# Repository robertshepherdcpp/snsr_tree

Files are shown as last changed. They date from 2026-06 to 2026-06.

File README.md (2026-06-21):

# snsr_tree
a tree with all the sensors you need to stay healthy!
 


## inspiration
- i have always wanted some sensors for my room, however, they are expensive and involve constantly checking the readings.
- so i thought it would be cool to make my own, where all these sensors are merged into one thing — and if certain levels were too high, it would actually tell me to change them!
- i wanted it to be something that sits in my room, so i decided to make it the shape of a tree (to blend in with the plants on my desk).

## how to use
1. get the PCB and case printed, and buy all the parts (listed in the BOM — total cost: $82.23)
2. paint the case green as shown in the 3D renders
3. download the audio files (mp3) from this repository and save them onto an SD card (32GB)
4. insert the SD card into the SD card holder on the PCB
5. assemble the case using screws, which also go through the PCB
6. plug into a computer and flash the firmware (in this repository) to the XIAO-ESP32-C6 — easiest via the Arduino IDE
7. keep plugged into the computer, as it is the project's power source
8. use the project and listen out for warnings!

## what it is / how it works
- the snsr_tree takes readings of different environmental levels: CO2, humidity, temperature, and light
- based on those readings, it will alert you to change certain levels — or in some cases do it for you (e.g. when it's too dark)
- keeping you informed about the conditions in your room!
  
## features
- WiFi communication for RTC (real-time clock sync)
- I2C protocol for sensor communication

## screenshots
 
the 3D case:
 


the schematic:
 


the PCB wiring:
 


PCB 3D model:



BOM:
| Name | Price  | Link |
|---|---|---|
| SCD40 | $19.60 | https://www.aliexpress.com/item/1005004251901089.html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 |
| ICS-43434 | $3.43  | https://www.aliexpress.com/item/1005009682961260.html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 |
| MAX98357A Audio Amplifier | $1.32  | https://www.aliexpress.com/item/1005007003802663.html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 |
| MCP23017 | $1.81  | https://www.aliexpress.com/item/1005007892385986.html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 |
| XIAO-ESP32-C6 | $7.11  | https://www.aliexpress.com/item/1005008233414789.html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 |
| micro-sd card holder | $6.74  | https://www.aliexpress.com/item/1005008118445934.html |
| speaker | $0.82  | https://www.lcsc.com/product-detail/C530531.html?s_z=n_q_C530531&globalKeyword=C530531 |
| leds | $2.08  | https://www.aliexpress.com/item/1005010643263450.html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 |
| resistors - 15r | $2.72  | https://www.aliexpress.com/item/1005011892468044.html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 |
| resistors - 10k | $2.72  | https://www.aliexpress.com/item/1005011892468044.html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 |
| resistors - 4.7k | $2.72  | https://www.aliexpress.com/item/1005011892468044.html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 |
| resistors - 100k | $2.74  | https://www.aliexpress.com/item/1005011892468044.html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 |
| capcitor - 100nf | $0.76  | https://www.aliexpress.com/item/32371454429.html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 |
| capacitor - 10uF | $1.24  | https://www.aliexpress.com/item/1005007137284660.html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 |
| capacitor - 4.7uF | $1.24  | https://www.aliexpress.com/item/1005007137284660.html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 |
| capacitor - 1uF | $1.24  | https://www.aliexpress.com/item/1005007137284660.html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 |
| ldr | $1.02  | https://www.aliexpress.com/item/1005004112010040.html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 |
| m2 12mm screws | $2.11  | https://www.aliexpress.com/item/1005008143416203.html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 |
| pcb fabrication | $10.10 | https://cart.jlcpcb.com/quote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 |
| shipping | $10.71 | https://cart.jlcpcb.com/quote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 |
| total cost | $82.23 | - |

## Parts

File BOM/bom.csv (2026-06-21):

Name | Price | Link
SCD40 | $19.60 | https://www.aliexpress.com/item/1005004251901089.html?curPageLogUid=Gt4emBnw6aWf
ICS-43434 | $3.43 | https://www.aliexpress.com/item/1005009682961260.html?curPageLogUid=vnISMVQXcKGG
MAX98357A Audio Amplifier | $1.32 | https://www.aliexpress.com/item/1005007003802663.html?curPageLogUid=jVDx2fWExivP
MCP23017 | $1.81 | https://www.aliexpress.com/item/1005007892385986.html?curPageLogUid=5EILj2DePQUk
XIAO-ESP32-C6 | $7.11 | https://www.aliexpress.com/item/1005008233414789.html?curPageLogUid=3Z71R6KGLr0g
micro-sd card holder | $6.74 | https://www.aliexpress.com/item/1005008118445934.html
speaker | $0.82 | https://www.lcsc.com/product-detail/C530531.html?s_z=n_q_C530531&globalKeyword=C530531
leds | $2.08 | https://www.aliexpress.com/item/1005010643263450.html?curPageLogUid=BF1YAVMOhfXj
resistors - 15r | $2.72 | https://www.aliexpress.com/item/1005011892468044.html?curPageLogUid=lUmGxkF3KGzQ
resistors - 10k | $2.72 | https://www.aliexpress.com/item/1005011892468044.html?curPageLogUid=lUmGxkF3KGzQ
resistors - 4.7k | $2.72 | https://www.aliexpress.com/item/1005011892468044.html?curPageLogUid=lUmGxkF3KGzQ
resistors - 100k | $2.74 | https://www.aliexpress.com/item/1005011892468044.html?curPageLogUid=lUmGxkF3KGzQ
capcitor - 100nf | $0.76 | https://www.aliexpress.com/item/32371454429.html?curPageLogUid=dIjc8NwSzsQi
capacitor - 10uF | $1.24 | https://www.aliexpress.com/item/1005007137284660.html?curPageLogUid=9b90RMqDifxh
capacitor - 4.7uF | $1.24 | https://www.aliexpress.com/item/1005007137284660.html?curPageLogUid=9b90RMqDifxh
capacitor - 1uF | $1.24 | https://www.aliexpress.com/item/1005007137284660.html?curPageLogUid=9b90RMqDifxh
ldr | $1.02 | https://www.aliexpress.com/item/1005004112010040.html?curPageLogUid=cZMJc4zObGdm
m2 12mm screws | $2.11 | https://www.aliexpress.com/item/1005008143416203.html?curPageLogUid=cFyM0bsjev7p
pcb fabrication | $10.10 | https://cart.jlcpcb.com/quote?stencilLayer=2&stencilWidth=100&stencilLength=100&stencilCounts=5&plateType=1
shipping | $10.71 | https://cart.jlcpcb.com/quote?stencilLayer=2&stencilWidth=100&stencilLength=100&stencilCounts=5&plateType=1
total cost | $82.23 | -

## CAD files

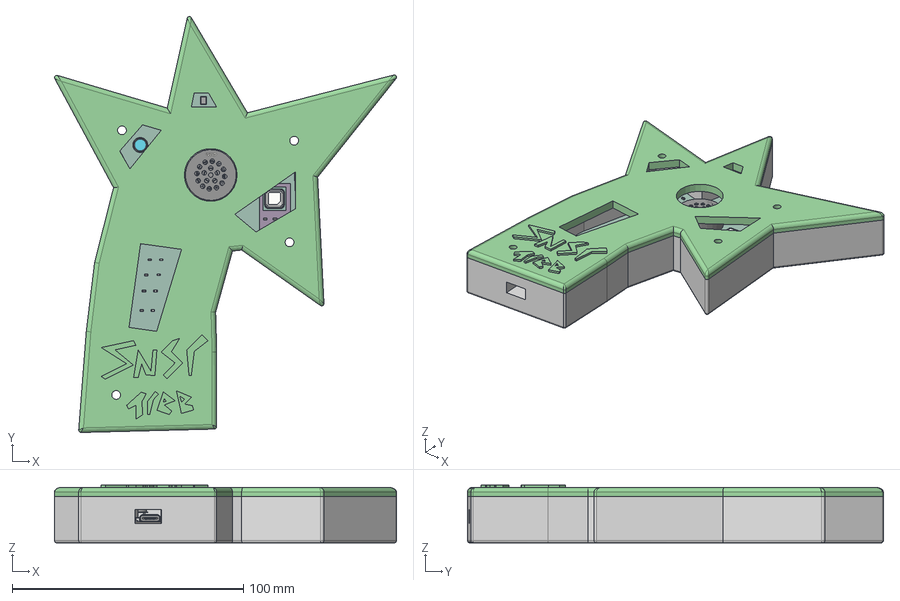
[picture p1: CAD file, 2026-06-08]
3d/snsr_tree v2.step
148.0 x 180.0 x 25.0 mm
SPK-TH_BD23.0-P10.00-D0.8-L-RD
InvenSense_ICS-43434-6_3.5x2.65mm
LED_0603_1608Metric x 4
R_LDR_D6.4mm_P3.4mm_Vertical
R_0603_1608Metric x 8
QFN-28_L6.0-W6.0-P0.65-BL-EP3.7
C_0603_1608Metric
microSD_HC_Hirose_DM3AT-SF-PEJM5
environment_proj_PCB
BOSS-EXTRUDE14_8_
BOSS-EXTRUDE7_4_
BOSS-EXTRUDE7_3_
BOSS-EXTRUDE14_4_
BOSS-EXTRUDE14_2_
BOSS-EXTRUDE14_11_
BOSS-EXTRUDE7_7_
BOSS-EXTRUDE14_9_
BOSS-EXTRUDE14_3_
BOSS-EXTRUDE14_7_
MIRROR2
BOSS-EXTRUDE14_5_
BOSS-EXTRUDE14_12_
BOSS-EXTRUDE7_8_
BOSS-EXTRUDE7_1_
BOSS-EXTRUDE14_10_
BOSS-EXTRUDE7_9_
BOSS-EXTRUDE14_6_
BOSS-EXTRUDE14_1_
BOSS-EXTRUDE7_6_
BOSS-EXTRUDE7_2_
CUT-EXTRUDE5
BOSS-EXTRUDE7_5_
Shield
Pins x 2
U.FL-R-SMT-1_10_ v1
Komponente1
Komponente1 (1)
Komponente2
Komponente3

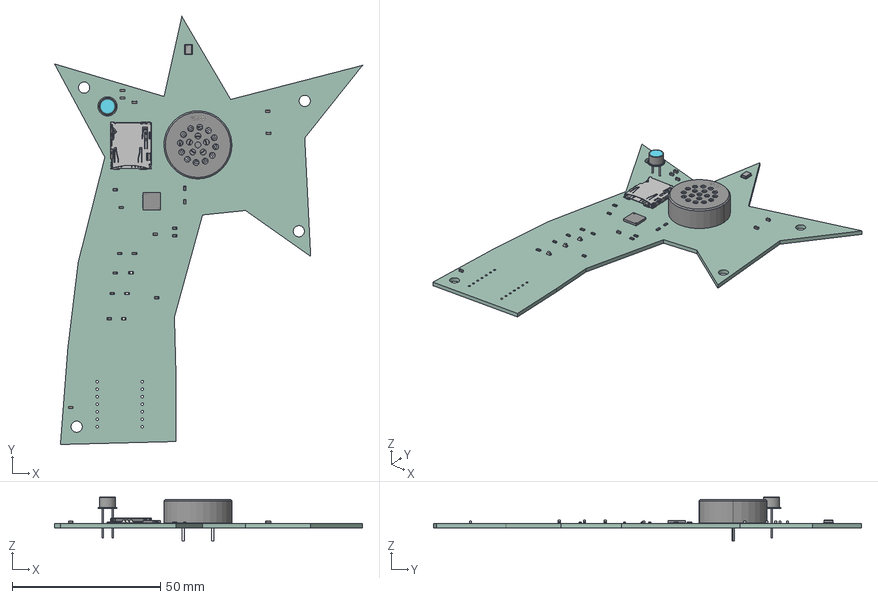
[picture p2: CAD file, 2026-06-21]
PCB/environment_proj.step
104.0 x 144.5 x 14.8 mm
SPK-TH_BD23.0-P10.00-D0.8-L-RD
R_0603_1608Metric x 12
InvenSense_ICS-43434-6_3.5x2.65mm
C_0603_1608Metric x 7
LED_0603_1608Metric x 3
R_LDR_D6.4mm_P3.4mm_Vertical
QFN-28_L6.0-W6.0-P0.65-BL-EP3.7
microSD_HC_Hirose_DM3AT-SF-PEJM5
environment_proj_PCB

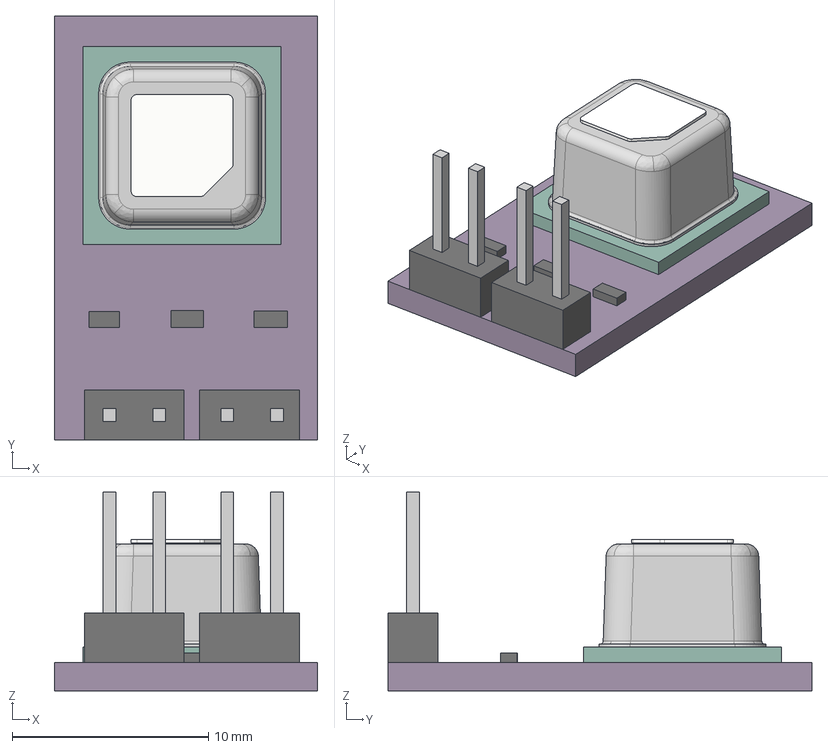
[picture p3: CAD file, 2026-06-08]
3d/scd40 v7.step
13.4 x 21.6 x 10.1 mm
Komponente1
Komponente1 (1)
Komponente2
Komponente3

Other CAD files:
3d/environment_proj.step
3d/snsr_tree v2.f3z

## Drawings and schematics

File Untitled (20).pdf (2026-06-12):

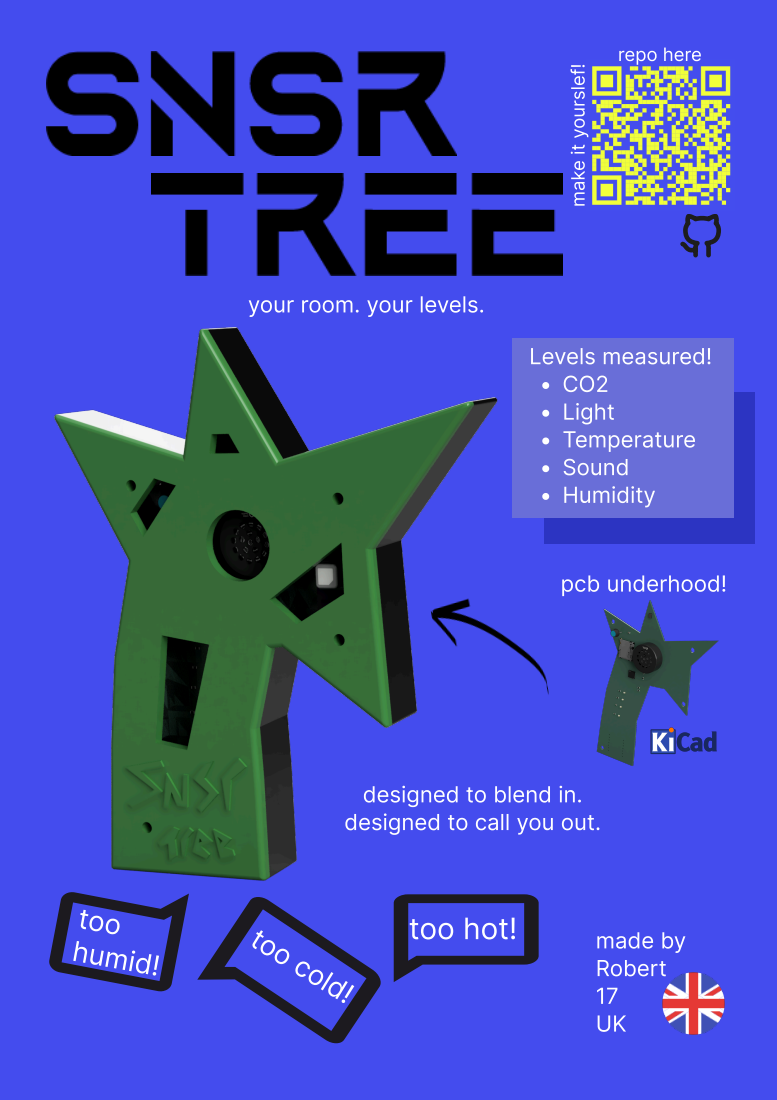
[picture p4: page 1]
repo here; Levels measured! CO2 Light Temperature; Sound Humidity; pcb underhood!; too humid!; made by; Robert 17 UK

make it yourslef!

your room. your levels.

designed to blend in.
designed to call you out.

too hot! too cold!

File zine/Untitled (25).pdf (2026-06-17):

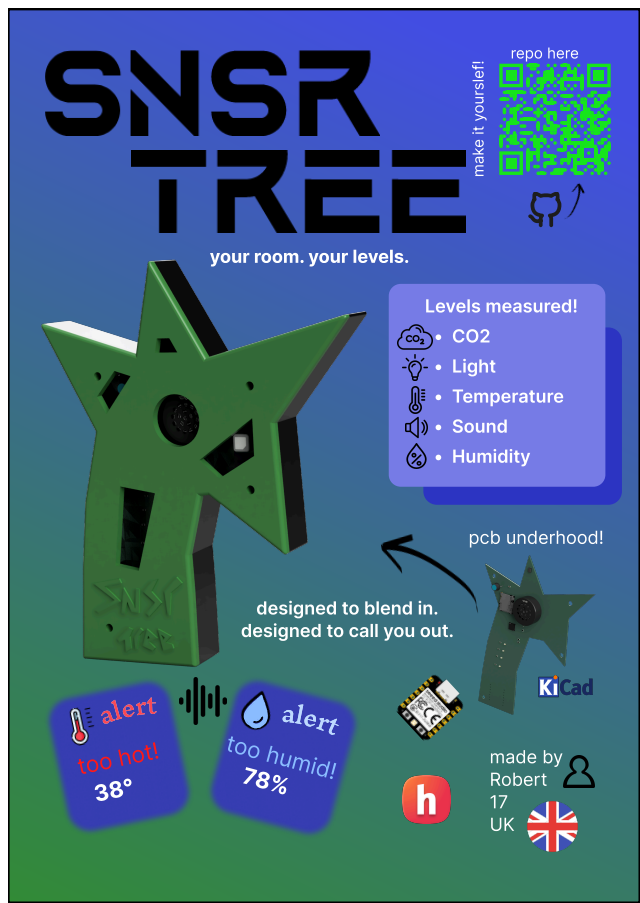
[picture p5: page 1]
repo here; Levels measured!; Light; Temperature; Sound; Humidity; pcb underhood!; too hot! too hot!; too humid!; made by; Robert

make it yourslef!

your room. your levels.

designed to blend in.
designed to call you out.

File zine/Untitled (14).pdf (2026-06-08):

# snsrtree

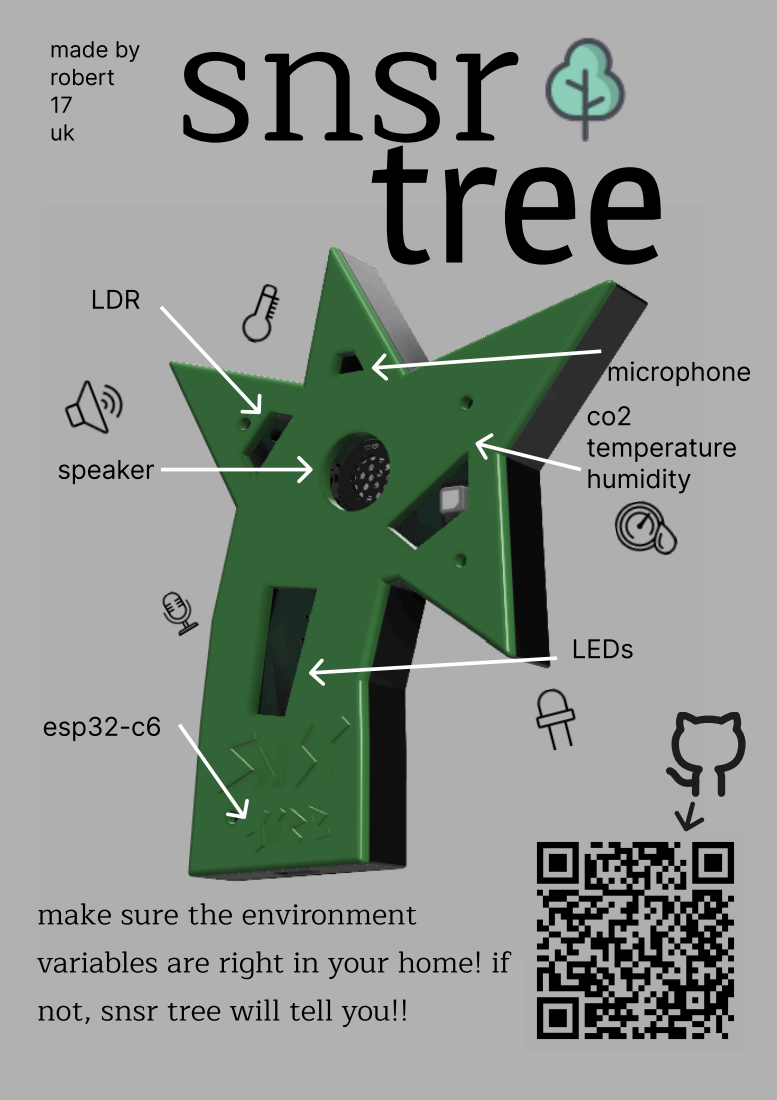
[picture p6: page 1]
made by robert 17 uk; LDR; speaker; microphone; co2 temperature humidity; esp32-c6; LEDs

make sure the environment
variables are right in your home! if
not, snsr tree will tell you!!

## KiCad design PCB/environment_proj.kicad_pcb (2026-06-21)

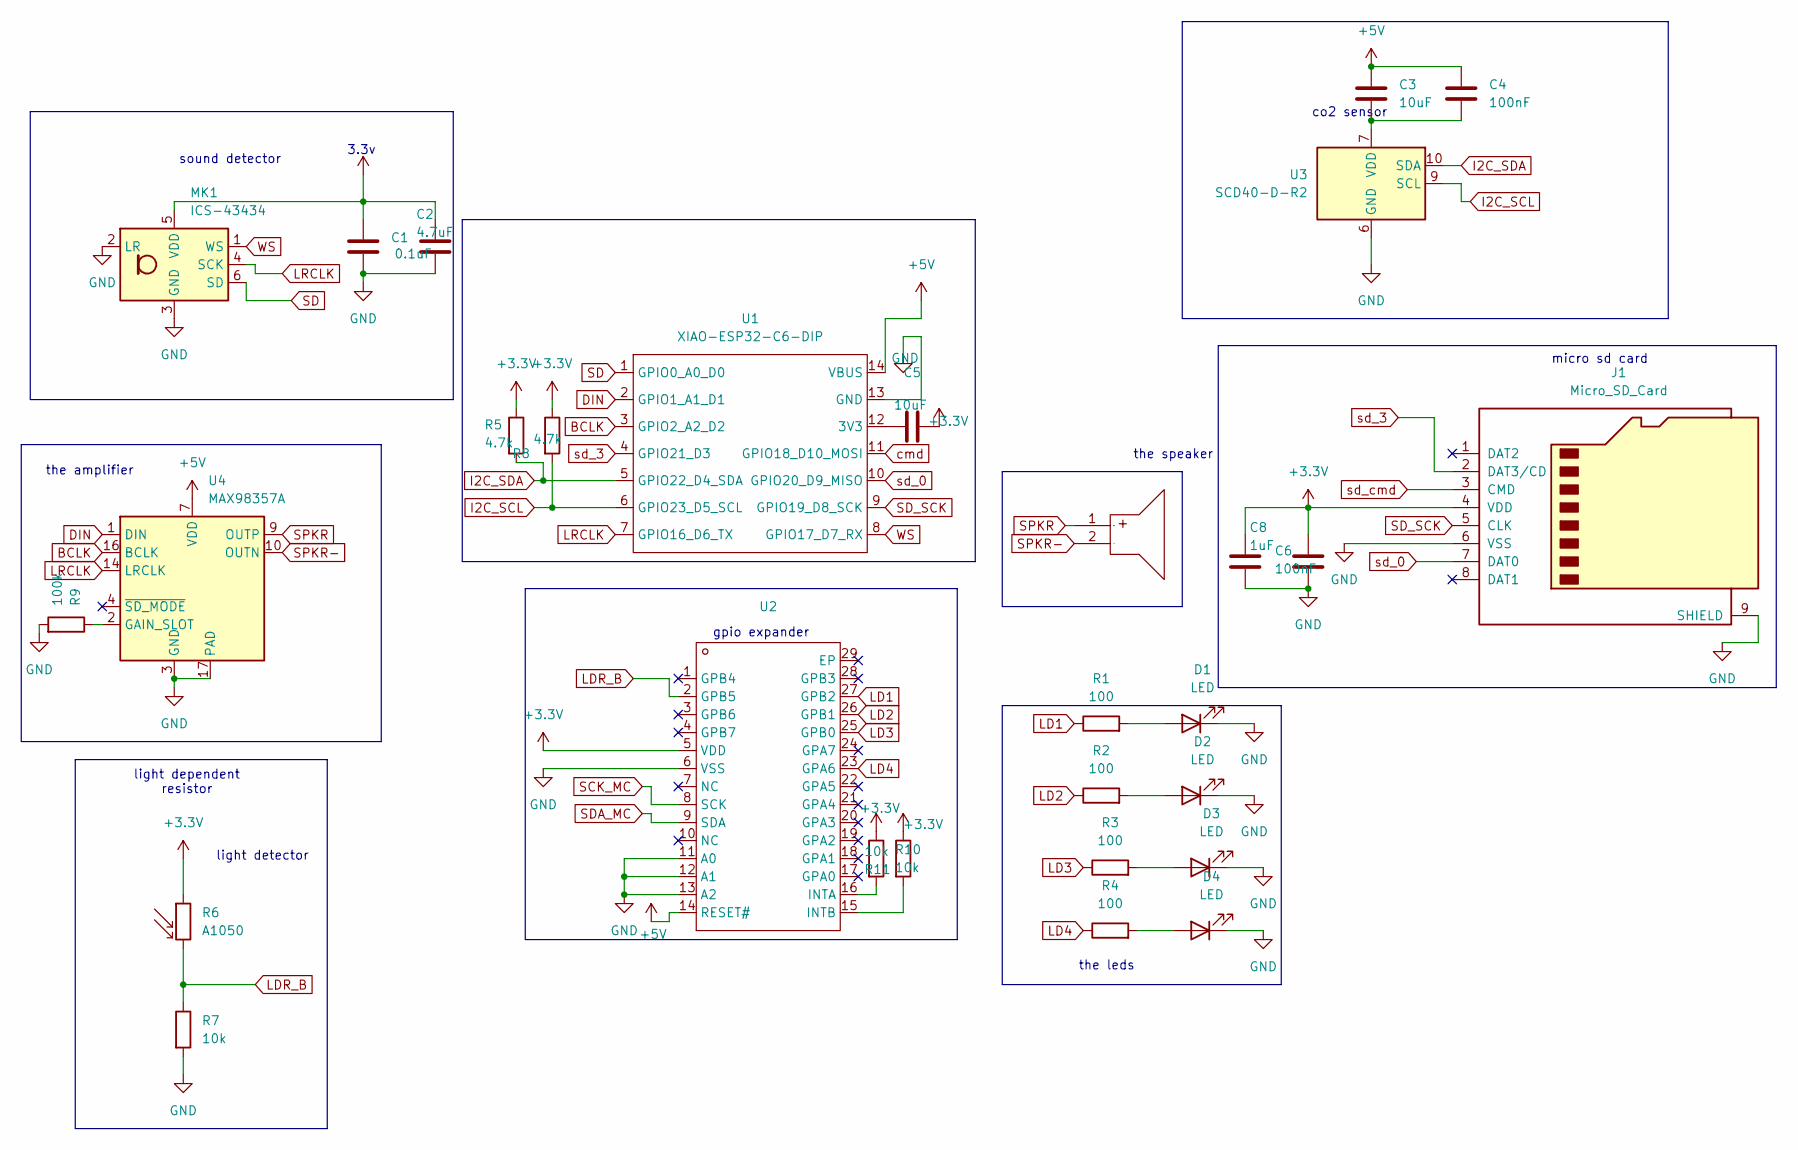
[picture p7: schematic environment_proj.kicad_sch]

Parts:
C1: 0.1uF; C_0603_1608Metric_Pad1.08x0.95mm_HandSolder
C2: 4.7uF; C_0603_1608Metric
C3, C5: 10uF; C_0603_1608Metric
C4, C6: 100nF; C_0603_1608Metric
C8: 1uF; C_0603_1608Metric
D1: LED; R_0603_1608Metric_Pad0.98x0.95mm_HandSolder
D2, D3, D4: LED; LED_0603_1608Metric_Pad1.05x0.95mm_HandSolder
J1: Micro_SD_Card; microSD_HC_Hirose_DM3AT-SF-PEJM5
MK1: ICS-43434; InvenSense_ICS-43434-6_3.5x2.65mm
R1, R2, R3, R4: 100; R_0603_1608Metric_Pad0.98x0.95mm_HandSolder
R5, R8: 4.7k; R_0603_1608Metric_Pad0.98x0.95mm_HandSolder
R6: A1050; R_LDR_D6.4mm_P3.4mm_Vertical
R7, R10, R11: 10k; R_0603_1608Metric_Pad0.98x0.95mm_HandSolder
R9: 100k; R_0603_1608Metric_Pad0.98x0.95mm_HandSolder
SPK4: SPK-TH_BD23.0-P10.00-D0.8-L-RD; Manufacturer Part GSPK2307P-8R1W; LCSC Part Name 23mm 8Ω
U1: XIAO-ESP32-C6-DIP
U2: QFN-28_L6.0-W6.0-P0.65-BL-EP3.7; Manufacturer Part MCP23017T-E/ML; LCSC Part Name 16位带串行接口的I/O扩展器
U3: SCD40-D-R2; Sensirion_SCD4x-1EP_10.1x10.1mm_P1.25mm_EP4.8x4.8mm
U4: MAX98357A; TQFN-16-1EP_3x3mm_P0.5mm_EP1.23x1.23mm

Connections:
+3.3V: C1.1, C2.1, C5.2, C6.1, C8.1, J1.4 (VDD), MK1.5 (VDD), R5.1, R6.1, R8.1, R10.1, R11.1, U2.5 (VDD)
+5V: C3.1, C4.1, U1.14 (VBUS), U2.14 (RESET#), U4.7 (VDD), U4.8 (VDD)
BCLK: U1.3 (GPIO2_A2_D2), U4.16 (BCLK)
DIN: U1.2 (GPIO1_A1_D1), U4.1 (DIN)
GND: C1.2, C2.2, C6.2, C8.2, D1.1 (K), D2.1 (K), D3.1 (K), D4.1 (K), J1.6 (VSS), J1.9 (SHIELD), MK1.2 (LR), MK1.3 (GND), R7.2, R9.2, U1.13 (GND), U2.6 (VSS), U2.11 (A0), U2.12 (A1), U2.13 (A2), U3.6 (GND), U3.20 (GND), U3.21 (GND), U4.3 (GND), U4.11 (GND), U4.15 (GND), U4.17 (PAD)
I2C_SCL: R8.2, U1.6 (GPIO23_D5_SCL), U3.9 (SCL)
I2C_SDA: R5.2, U1.5 (GPIO22_D4_SDA), U3.10 (SDA)
LD1: R1.1, U2.27 (GPB2)
LD2: R2.1, U2.26 (GPB1)
LD3: R3.1, U2.25 (GPB0)
LD4: R4.1, U2.23 (GPA6)
LDR_B: R6.2, R7.1, U2.2 (GPB5)
LRCLK: MK1.4 (SCK), U1.7 (GPIO16_D6_TX), U4.14 (LRCLK)
unnamed: C3.2, C4.2, U3.7 (VDD), U3.19 (VDD)
unnamed: D1.2 (A), R1.2
unnamed: D2.2 (A), R2.2
unnamed: D3.2 (A), R3.2
unnamed: D4.2 (A), R4.2
unnamed: C5.1, U1.12 (3V3)
unnamed: R10.2, U2.16 (INTA)
unnamed: R11.2, U2.15 (INTB)
unnamed: R9.1, U4.2 (GAIN_SLOT)
SCK_MC: U2.8 (SCK)
SD: MK1.6 (SD), U1.1 (GPIO0_A0_D0)
SDA_MC: U2.9 (SDA)
SD_SCK: J1.5 (CLK), U1.9 (GPIO19_D8_SCK)
SPKR: SPK4.1 (+), U4.9 (OUTP); also elsewhere on the board
SPKR-: SPK4.2 (-), U4.10 (OUTN)
WS: MK1.1 (WS), U1.8 (GPIO17_D7_RX)
cmd: U1.11 (GPIO18_D10_MOSI)
sd_0: J1.7 (DAT0), U1.10 (GPIO20_D9_MISO)
sd_3: J1.2 (DAT3/CD), U1.4 (GPIO21_D3)
sd_cmd: J1.3 (CMD)

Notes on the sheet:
the amplifier
light detector
the speaker
micro sd card
3.3v
co2 sensor
the leds
gpio expander
sound detector
light dependent resistor

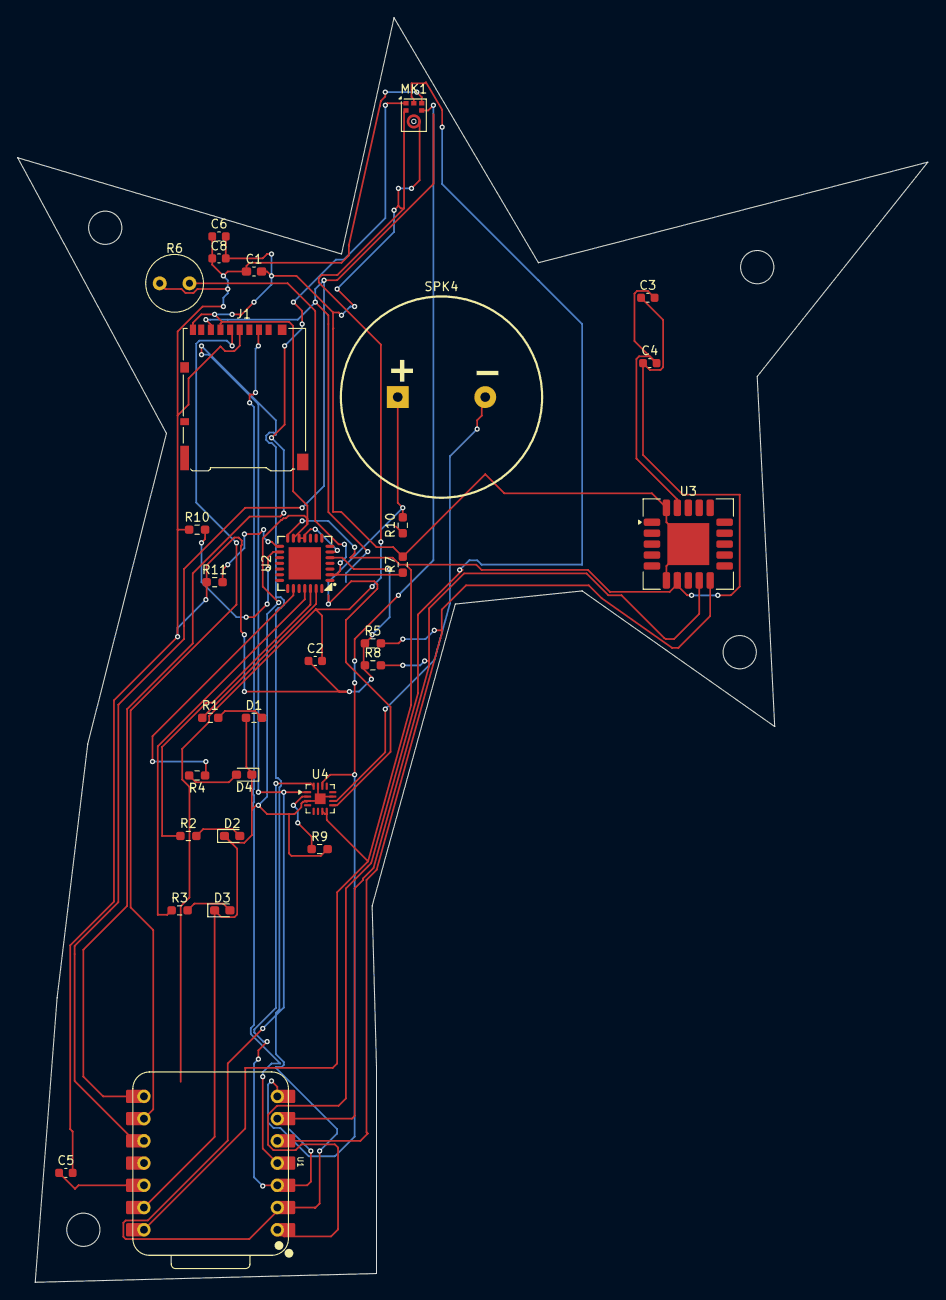
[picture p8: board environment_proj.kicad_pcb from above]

Board: 2 copper layers, 104.0 x 144.5 mm, 30 parts (0 on the bottom side), 29 nets.

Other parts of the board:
R10#2: 8; R_0603_1608Metric_Pad0.98x0.95mm_HandSolder

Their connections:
SPKR: R10#2.2; also elsewhere on the board

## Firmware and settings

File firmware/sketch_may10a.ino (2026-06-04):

#include <Wire.h>
#include <Audio.h>
#include <SPI.h>
#include <Wire.h>
#include <Arduino.h>
#include <SensirionI2cScd4x.h>
#include <SD.h>
#include <Adafruit_MCP23X17.h>

// microphone stuff
#include "I2SSampler.h"

i2s_config_t i2s_config = {
  .mode = (i2s_mode_t)(I2S_MODE_MASTER | I2S_MODE_RX),
  .sample_rate = 16000,
  .bits_per_sample = I2S_BITS_PER_SAMPLE_32BIT,
  .channel_format = I2S_CHANNEL_FMT_ONLY_LEFT,
  .communication_format = i2s_comm_format_t(I2S_COMM_FORMAT_I2S),
  .intr_alloc_flags = ESP_INTR_FLAG_LEVEL1,
  .dma_buf_count = 4,
  .dma_buf_len = 1024,
  .use_apll = false,
  .tx_desc_auto_clear = false,
  .fixed_mclk = 0
};

// i2s pins
i2s_pin_config_t i2s_pins = {
  .bck_io_num = GPIO_NUM_5,
  .ws_io_num = GPIO_NUM_19,
  .data_out_num = I2S_PIN_NO_CHANGE,
  .data_in_num = GPIO_NUM_18
};

I2SSampler *i2s_sampler = NULL;

// for getting the time via wifi:
#include <WiFi.h>
#include <NTPClient.h>
#include <WiFiUdp.h>

// replace with your network credentials!! or else the project wont work... needed to get the time.
const char *ssid = "REPLACE_WITH_YOUR_SSID";
const char *password = "REPLACE_WITH_YOUR_PASSWORD";

// Define NTP Client to get time
WiFiUDP ntpUDP;
NTPClient timeClient(ntpUDP);

// Variables to save date and time
String formattedDate;
String dayStamp;
String timeStamp;

// on the esp32

#define LDR_B 6

// however need to check with these that i can just wire these like that
#define SDA_BUS 22
#define SDL_BUS 23

// on the mc23017, bank A: 1-8, bank b: 21-28

// #define SCK_MC TODO
// #define SCA_MC TODO

#define LED1 3
#define LED2 2
#define LED3 1
#define LED4 27

Adafruit_MCP23X17 mcp;

// i2c addresses
#define SCD40 0x62
// #define BME280 0x76  // could be 0x77 if SDO is connected to VCC

// humidity and temperature notes:
/*
humidity: 0-100% (recommended: 40-60)
temperature: -40-85 (recommended: 20-22)
*/

// humidity + temperature sensor
float humidity_percentage;
float temperature;  // in degrees

// microphone
int decibels;

// co2 levels ppm
uint16_t co2_levels;

// light levels in lux
int light_level;

// for the co2 sensor
SensirionI2cScd4x sensor;

static int16_t error;

bool nightTime = false;

/*
VALUES SORTED:

CO2 levels
temperature
humidity_percentage

light

sound input
*/

auto read_values() {
  // updating the time:
  while (!timeClient.update()) {
    timeClient.forceUpdate();
  }
  // The formattedDate comes with the following format:
  // 2018-05-28T16:00:13Z
  // We need to extract date and time
  formattedDate = timeClient.getFormattedDate();
  Serial.println(formattedDate);

  // get the hour.
  int splitT = formattedDate.indexOf("T");
  timeStamp = formattedDate.substring(splitT + 1, splitT + 3);
  int hour = timeStamp.toInt();

  if (hour <= 7 || hour >= 22) {
    nightTime = true;
  } else {
    nightTime = false;
  }

  // reading from the co2 sensor
  bool dataReady = false;
  uint16_t co2Concentration = 0;  // in ppm
  float temp = 0.0;               // in degrees
  float relativeHumidity = 0.0;   // percentage

  delay(5000);

  error = sensor.getDataReadyStatus(dataReady);
  if (error != NO_ERROR) {
    return;
  }

  while (!dataReady) {
    delay(100);
    error = sensor.getDataReadyStatus(dataReady);
    if (error != NO_ERROR)
      return;
  }

  error = sensor.readMeasurement(co2Concentration, temp, relativeHumidity);
  if (error != NO_ERROR) {
    return;
  }

  humidity_percentage = relativeHumidity;
  co2_levels = co2Concentration;
  temperature = temp;

  // read light intensity
  int ldrValue = 0;
  ldrValue = mcp.analogRead(LDR_B);  // well say that the threshhold is 600 and if it is less than that we will put the lights on.
  light_level = ldrValue;

  // read the sound input:
  if (amplitudeAnalyzer.available()) {
    // read the new amplitude
    int amplitude = amplitudeAnalyzer.read();
    // then turn it into decibels
    int decibels = 20 * log10(abs(amplitude));  // greater than 80, we tell user to put it down.
  }
}

bool lightsOn = false;

// files needed: humidity_up, humidity_down, temp_up, temp_down all .mp3 files in sd card

auto handle_values() {

  // handling the humidifier
  if (humidity_percentage < 40) {
    // audio saying: "its a bit dry in here, but your humidifier on!"
    if (!played) {
      audio.connecttoFS(SD, "/humidity_up.mp3");
      played = true;
    }
    delay(3000);
  } else if (humidity_percentage > 60) {
    // audio saying: "its a bit humid in here! maybe put your dehumidifier on!"
    if (!played) {
      audio.connecttoFS(SD, "/humidity_down.mp3");
      played = true;
    }
    delay(3000);
  }

  // handling temperature
  if (temperature < 19) {
    // audio saying, put the temperature up!
    if (!played) {
      audio.connecttoFS(SD, "/temp_up.mp3");
      played = true;
    }
    delay(3000);
  }

  if (temperature > 23) {
    // audio saying: its a bit warm in here, try cooling down!
    if (!played) {
      audio.connecttoFS(SD, "/temp_down.mp3");
      played = true;
    }
    delay(3000);
  }

  // handling the sound.
  if (decibels > 80) {
    // flash the leds 3 times (because playing audio would be kinda silly)
    for (int i = 0; i < 3; i++) {
      mcp.digitalWrite(LED1, HIGH);
      mcp.digitalWrite(LED2, HIGH);
      mcp.digitalWrite(LED3, HIGH);
      mcp.digitalWrite(LED4, HIGH);
      delay(500);
      mcp.digitalWrite(LED1, LOW);
      mcp.digitalWrite(LED2, LOW);
      mcp.digitalWrite(LED3, LOW);
      mcp.digitalWrite(LED4, LOW);
      delay(500);
    }
  }

  // handling the co2
  if (co2_levels > 5000) {
    // audio saying: "co2 levels too high, open your windows!"
    if (!played) {
      audio.connecttoFS(SD, "/co2_lower.mp3");
      played = true;
    }
    delay(3000);
  }

  if (light_level < 600 && !nightTime) {
    // put on LED lights.
    lightsOn = true;
    mcp.digitalWrite(LED1, HIGH);
    mcp.digitalWrite(LED2, HIGH);
    mcp.digitalWrite(LED3, HIGH);
    mcp.digitalWrite(LED4, HIGH);
  } else if (light_level >= 600 && lightsOn) {
    mcp.digitalWrite(LED1, LOW);
    mcp.digitalWrite(LED2, LOW);
    mcp.digitalWrite(LED3, LOW);
    mcp.digitalWrite(LED4, LOW);
  } else {
    played = false;
  }
}

// MICROPHONE STUFF

uint8_t *audio_buffer = NULL;
int buffersize_bytes = 0;

void i2sWriterTask(void *param) {
  const TickType_t xMaxBlockTime = pdMS_TO_TICKS(100);

  while (true) {
    uint32_t ulNotificationValue = ulTaskNotifyTake(pdTRUE, xMaxBlockTime);

    if (ulNotificationValue > 0) {
      audio_buffer = (uint8_t *)sampler->getCapturedAudioBuffer();
      buffersize_bytes = sampler->getBufferSizeInBytes();

      float x_Pascal = (float)raw_sample / (float)(1 << 23) * 20.0f;  // Convert RMS in Pascals to dBSPL
      float Lz = 20.0 * log10(rms / (20e-6));                         // sound in decibels
      decibels = Lz;
    }
  }
}

#define I2S_DOUT 1
#define I2S_BCLK 2
#define I2S_LRC 16

#define SD_SCK 19
#define SD_MISO 20
#define SD_MOSI 18
#define SD_CS 21

bool played = false;

void setup() {
  // sorting out the microphone:
  // i2s_sampler = new I2SSampler();
  // i2s_sampler->start(I2S_NUM_1, i2s_pins, i2s_config, 32768, writer_task_handle);

  Serial.begin(115200);

  // sorting out loading sounds from the sd card and playing them on the speaker.
  SPI.begin(SD_SCK, SD_MISO, SD_MOSI, SD_CS);

  if (!SD.begin(SD_CS)) {
    return;
  }

  audio.setPinout(I2S_BCLK, I2S_LRC, I2S_DOUT);
  audio.setVolume(12);

  // sorting out the microphone:
  i2s_sampler = new I2SSampler();
  TaskHandle_t writer_task_handle;
  xTaskCreate(i2sWriterTask, "I2S Writer Task", 4096, i2s_sampler, 1, &writer_task_handle);
  i2s_sampler->start(I2S_NUM_1, i2s_pins, i2s_config, 32768, writer_task_handle);

  // for the wifi:
  WiFi.begin(ssid, password);

  while (WiFi.status() != WL_CONNECTED) {
    delay(500);
    Serial.print(".");
  }

  timeClient.begin();
  timeClient.setTimeOffset(0);  // GMT time (here in Britain, change for if ur in a different location.)

  // setting up the LEDS
  mcp.pinMode(LED1, OUTPUT);
  mcp.pinMode(LED2, OUTPUT);
  mcp.pinMode(LED3, OUTPUT);
  mcp.pinMode(LED4, OUTPUT);

  // setting up the i2c channel
  Wire.begin();
  Serial.begin(115200);
  sensor.begin(Wire, SCD40_I2C_ADDR_62);

  // the microphone
  if (!AudioInI2S.begin(44100, 32)) {
    Serial.println("Failed to initialize I2S input!");
    while (1)
      ;
  }

  if (!amplitudeAnalyzer.input(AudioInI2S)) {
    Serial.println("Failed to set amplitude analyzer input!");
    while (1)
      ;
  }

  if (!SD.begin(SD_card_select)) {
    Serial.println("cant connect to the SD card....");
    return;
  }

  // Initialize file system
  SPIFFS.begin();

  // Create audio components
  file = new AudioFileSourceSD("/music.mp3");
  out = new AudioOutputI2S();
  out->setPinout(24);
  mp3 = new AudioGeneratorMP3();

  out->SetGain(0.16);  // setting the volume.

  // Start playback
  mp3->begin(file, out);
}

void loop() {
  read_values();
  handle_values();

  // Keep calling loop while playing
  if (mp3->isRunning()) {
    if (!mp3->loop())
      mp3->stop();
  } else {
    // Playback has stopped
  }

  audio.loop();
}

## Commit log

2026-05-14 Enhance README with project details and features
    Added project inspiration, assembly instructions, screenshots, and features.
2026-05-14 Add PCB 3D model image to README
    Added PCB 3D model image to the README.
2026-05-14 uploading the 3d step file
    [environment_proj.step]
2026-06-04 add the pcb files
    [environment_proj.kicad_pcb, environment_proj.kicad_sch, environment_proj.step]
2026-06-04 add the updated step file.
    [environment_proj.step]
2026-06-05 Update BOM with new component prices and links
    [bom.csv]
2026-06-08 add the 3d files
    [environment_proj.step, scd40 v7.step, snsr_tree v2.step]
2026-06-08 add the new pcb files
    [environment_proj.kicad_pcb, environment_proj.kicad_sch, environment_proj.step]
2026-06-08 Add images for 3D case, schematic, and PCB wiring
2026-06-09 adding the updated pcb files.
    [environment_proj.kicad_pcb, environment_proj.kicad_sch, environment_proj.step]
2026-06-09 add the fusion file.
    [snsr_tree v2.f3z]
2026-06-12 Update usage instructions in README
    Added a step to paint the case green in the usage instructions.
2026-06-21 add the bom
2026-06-21 Update README with new images for schematic and PCB
    Added additional images for schematic and PCB wiring.
2026-06-21 add updated pcb files
    [environment_proj.kicad_pcb, environment_proj.kicad_sch, environment_proj.step]
2026-06-21 Update BOM table with new prices and links
2026-06-21 Update PCB image and BOM in README
